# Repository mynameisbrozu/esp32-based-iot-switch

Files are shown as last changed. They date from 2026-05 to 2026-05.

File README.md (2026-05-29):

# ESP32 based iot switch
An IOT switch designed in KiCad based on ESP32-C5 and GDEY037T03 e-paper display. All electronic components were sourced from AliExpress (wanted to try something I guess).
## ESP32-C5
32-bit single-core RISC-V MCU running at up to 240 MHz with 29 GPIOs.

- Dual-band 2.4/5 GHz connectivity
- Wi-Fi 6
- BLE 5
- Zigbee and Thread support

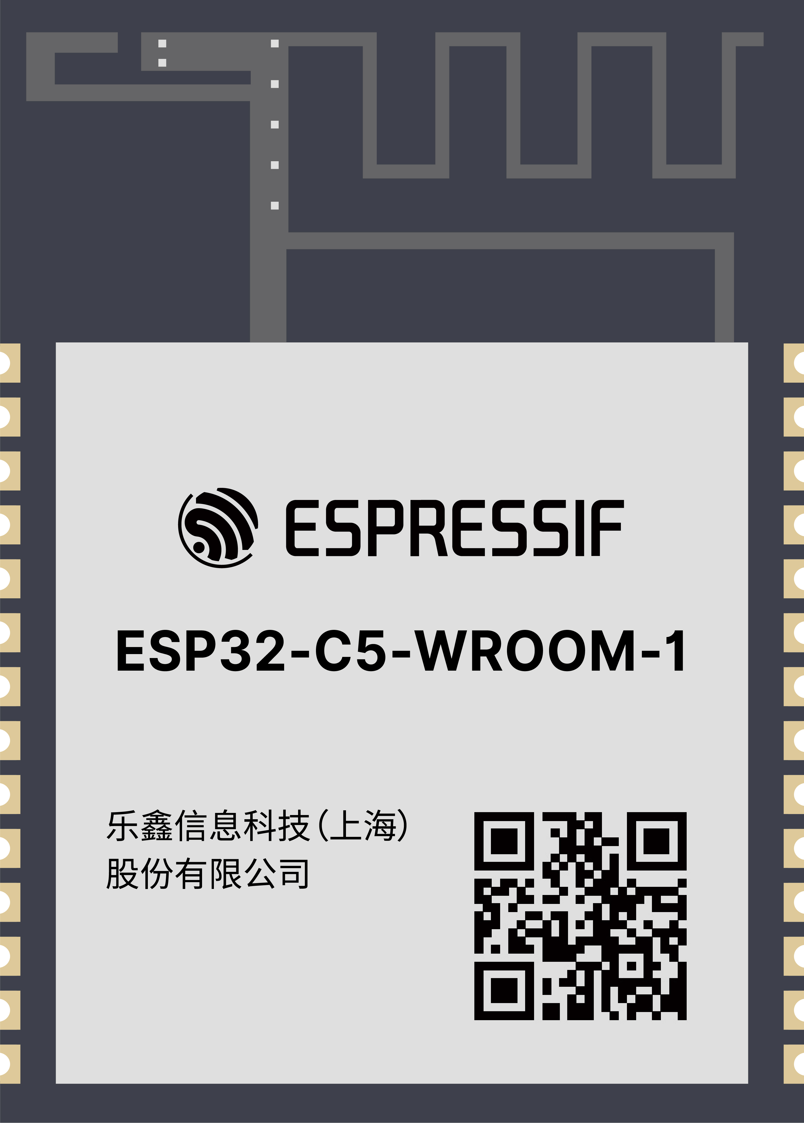
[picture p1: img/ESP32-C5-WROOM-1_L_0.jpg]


## GooDisplay GDEY037T03
3.7" black-and-white e-paper display.
- 240x416 resolution.
- 4-wire SPI interface

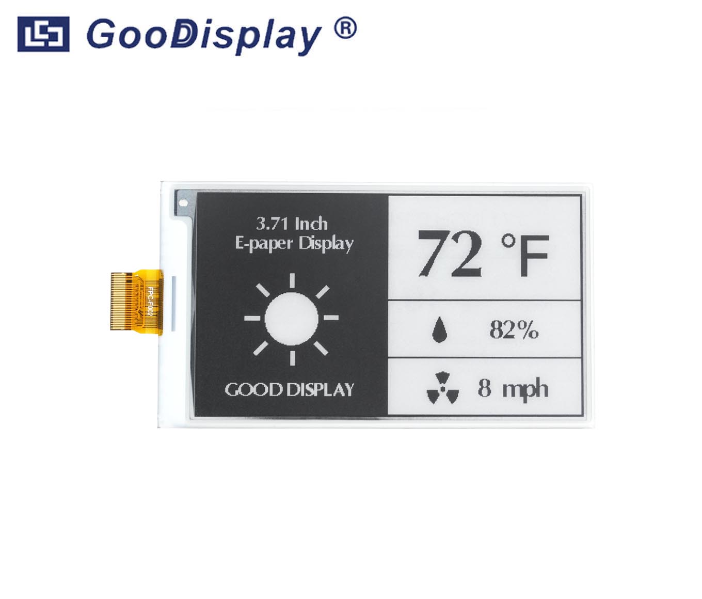
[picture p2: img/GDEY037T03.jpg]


## 1. Part sourcing and Power Budget
All components used in this project were sourced from AliExpress.

A simple system block diagram was created early in the design process to estimate the power budget and guide component selection.

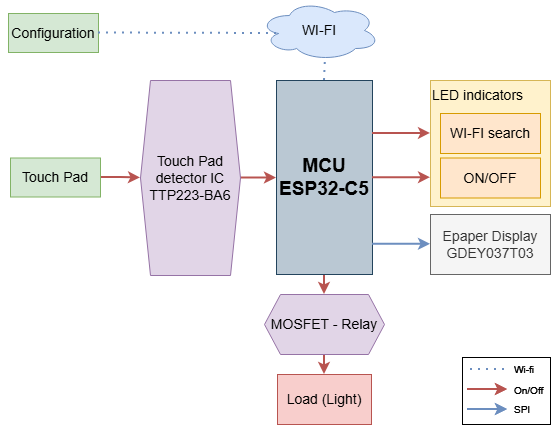
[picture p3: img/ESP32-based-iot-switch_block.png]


The BOM was progressively refined while developing the schematic. BOM in "spreadsheets" folder.
## 2. Schematic and PCB layout
The schematic was designed using reference circuits from datasheets, application notes, and technical articles.

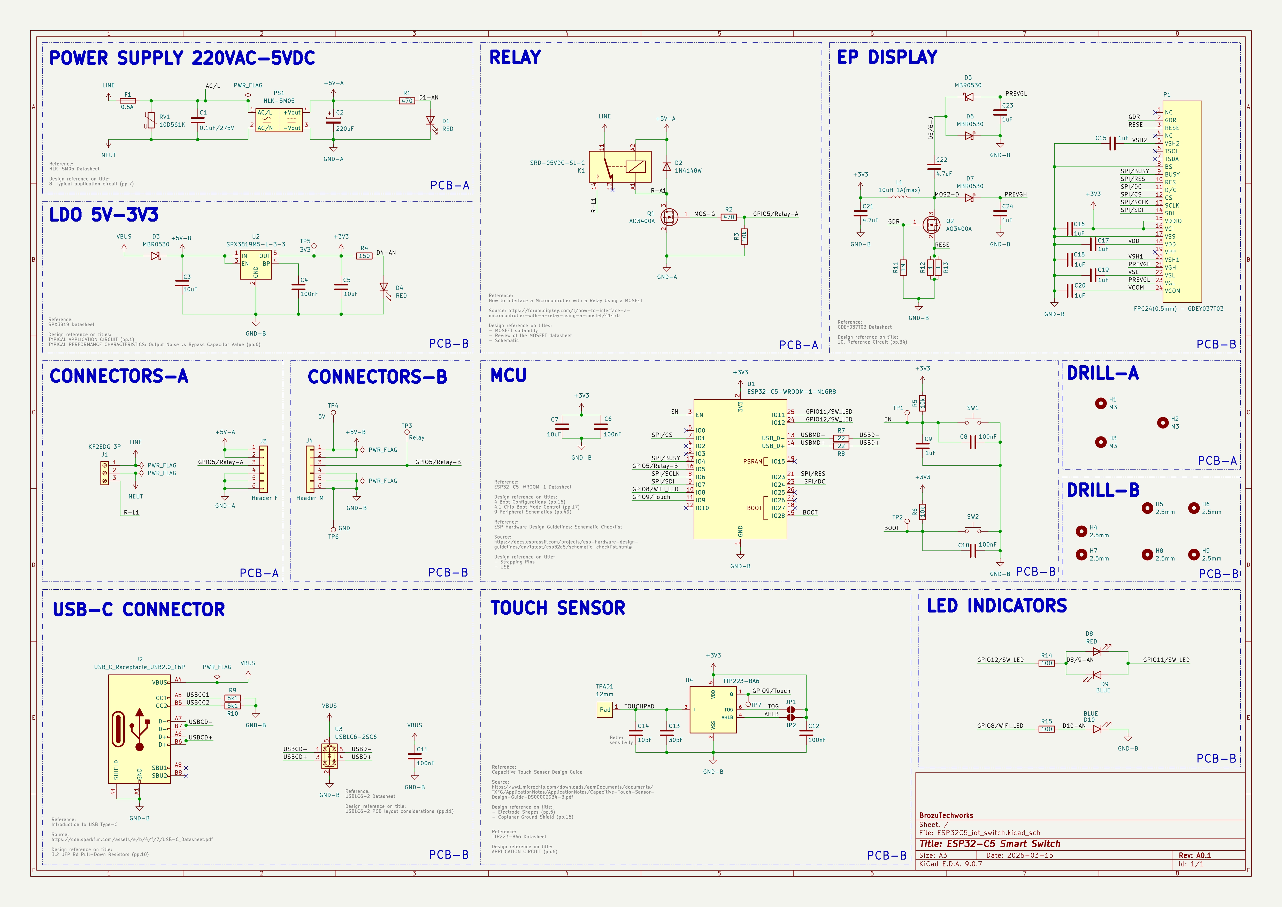
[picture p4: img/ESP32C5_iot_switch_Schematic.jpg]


The PCB layout show some of the mechanical constraints of the enclosure.

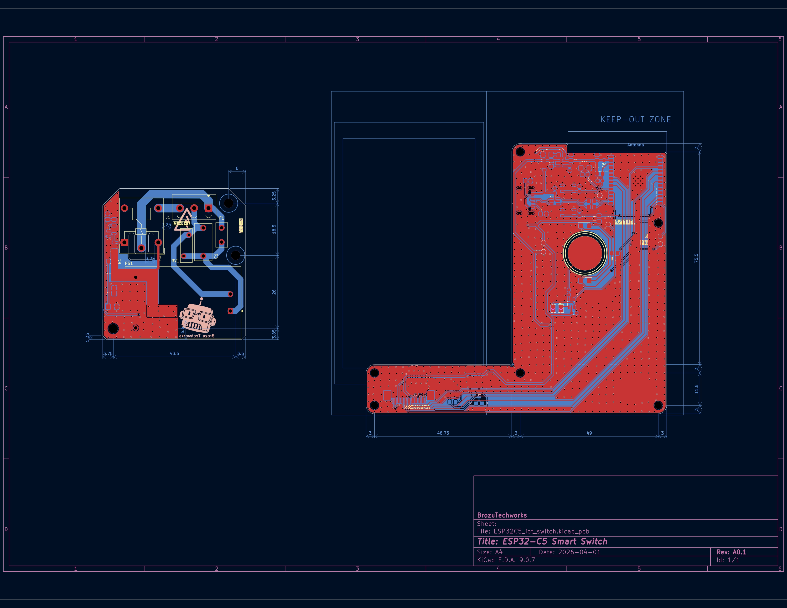
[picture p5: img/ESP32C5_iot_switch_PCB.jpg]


|  |  |
|---|---|
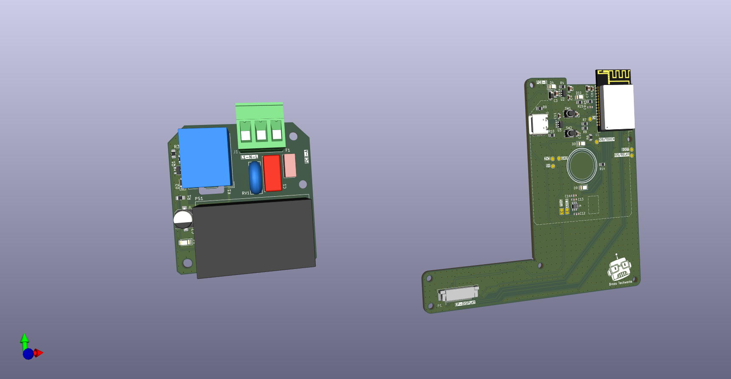
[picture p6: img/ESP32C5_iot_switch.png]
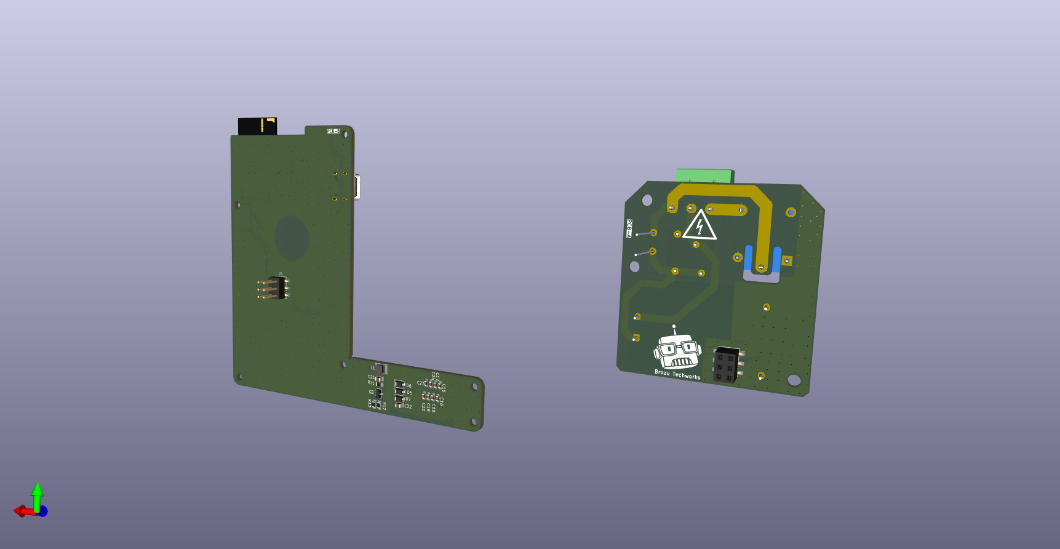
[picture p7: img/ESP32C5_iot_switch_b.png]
|  |  |
## 3. PCB Assembly
All components were manually assembled and soldered with a soldering iron (yeah...). 

PCB-A
|  |  |
|---|---|
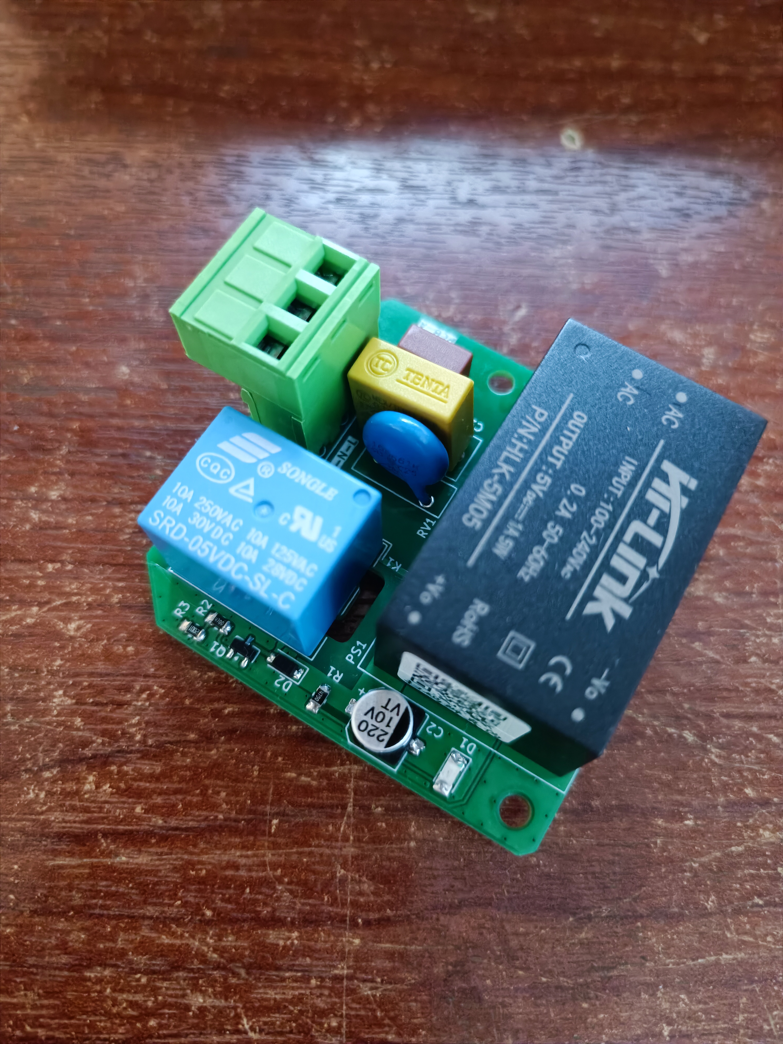
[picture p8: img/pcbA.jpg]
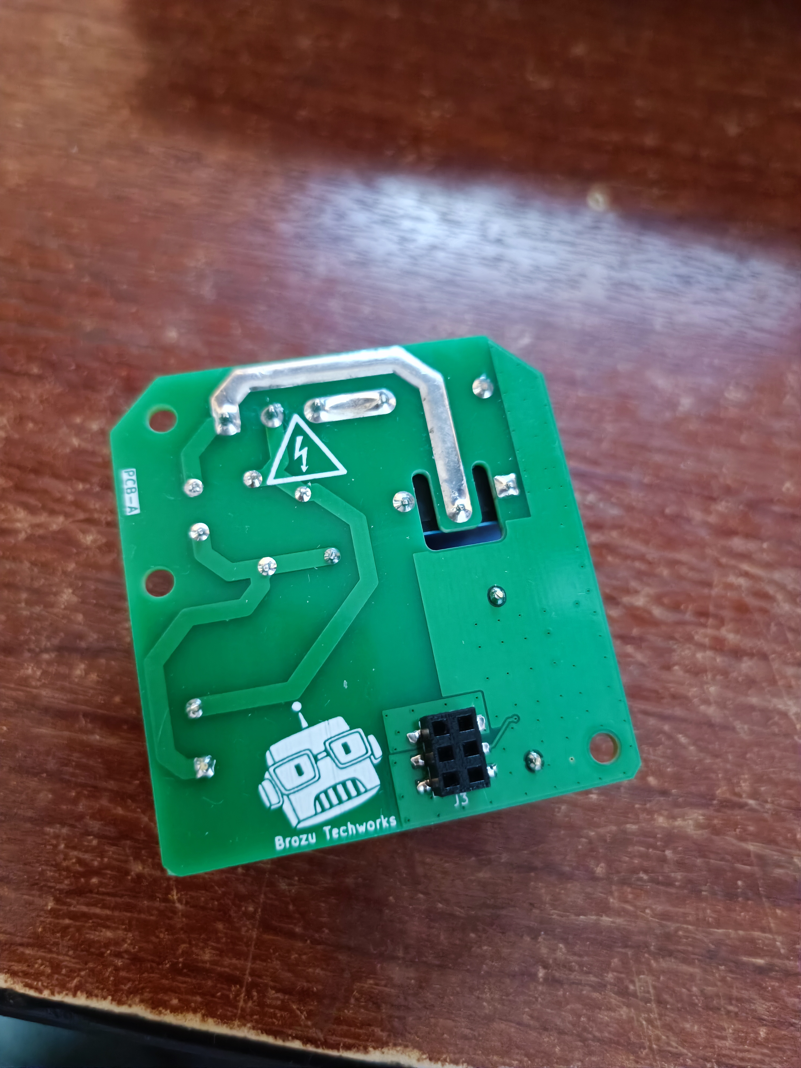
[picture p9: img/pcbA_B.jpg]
|  |  |

PCB-B
|  |  |
|---|---|
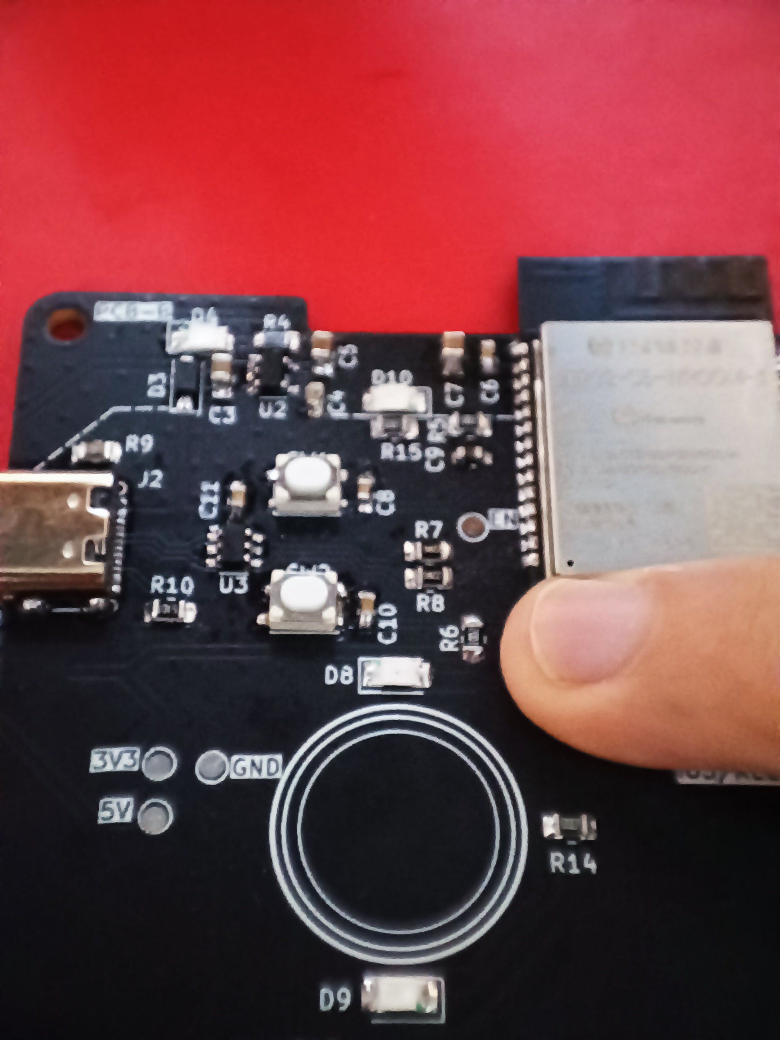
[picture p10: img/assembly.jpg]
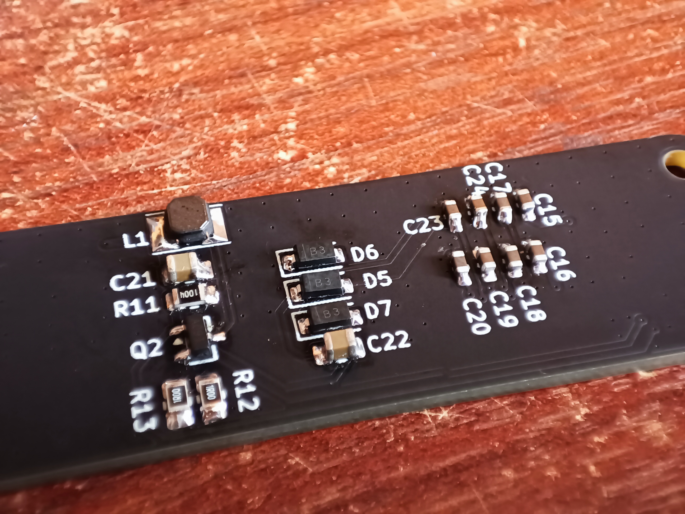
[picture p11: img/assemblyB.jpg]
|  |  |
## 4. Firmware...
Firmware development is still in progress.

Current work focuses on developing an integration library between the GDEY037T03 e-paper display and the Adafruit GFX library.

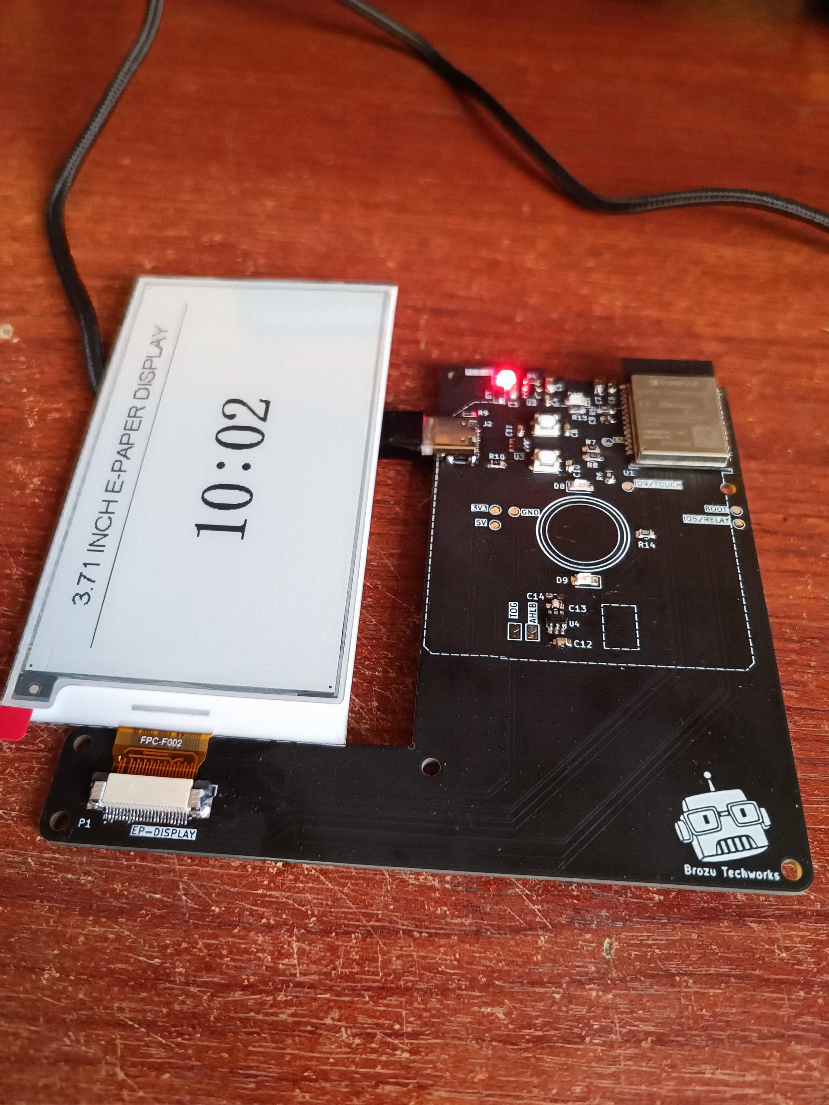
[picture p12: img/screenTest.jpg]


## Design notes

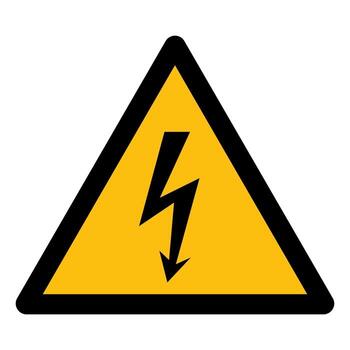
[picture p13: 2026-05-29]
PCB/silkscreen/danger-high-voltage.jpg

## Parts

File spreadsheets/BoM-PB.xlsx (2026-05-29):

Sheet: BoM
Bill of Materials
Block | Device | Description | Qty. | Buy Link | Pitch/Size
Power supply | 10D561K | Varistor | 1 | https://es.aliexpress.com/item/1005002576145968.html | 7.5mm
Relay | 1N4148W | FS Diode 75V 0.15 A | 1 | https://es.aliexpress.com/item/1005010653199938.html | SOD-123
Display | AO3400A | N-Channel MOSFET | 1 | https://es.aliexpress.com/item/1005007115799728.html | SOT-23
Relay | AO3400A | N-Channel MOSFET | 1 | https://es.aliexpress.com/item/1005007115799728.html | SOT-23
Display | Ceramic capacitor | 1uF 25V X7R | 8 | https://es.aliexpress.com/item/1005007464553853.html | 0603
Display | Ceramic capacitor | 4.7uF 25V X7R | 2 | https://es.aliexpress.com/item/1005007464553853.html | 0805
MCU | Ceramic capacitor | 100nF 25V X7R | 1 | https://es.aliexpress.com/item/1005007470747384.html | 0603
MCU | Ceramic capacitor | 100nF 25V X7R | 2 | https://es.aliexpress.com/item/1005007470747384.html | 0603
MCU | Ceramic capacitor | 10uF 25V X7R | 1 | https://es.aliexpress.com/item/1005007464553853.html | 0805
MCU | Ceramic capacitor | 1uF 25V X7R | 1 | https://es.aliexpress.com/item/1005007470747384.html | 0603
Power regulator | Ceramic capacitor | 100nF 25V X7R | 1 | https://es.aliexpress.com/item/1005007470747384.html | 0603
Power regulator | Ceramic capacitor | 10uF 25V X7R | 2 | https://es.aliexpress.com/item/1005007464553853.html | 0805
Touch button | Ceramic capacitor | 100nF 25V X7R | 1 | https://es.aliexpress.com/item/1005007470747384.html | 0603
Touch button | Ceramic capacitor | 10pF | 1 | https://es.aliexpress.com/item/1005006186888242.html | 0603
Touch button | Ceramic capacitor | 30pF | 1 | https://es.aliexpress.com/item/1005006186888242.html | 0603
USB | Ceramic capacitor | 100nF 25V X7R | 1 | https://es.aliexpress.com/item/1005007470747384.html | 0603
MCU | ESP32-C5-WROOM-1-N16R8 | 8MB FLASH/8MB PSRAM/PCB ANTENNA | 1 | https://es.aliexpress.com/item/1005008833493839.html | -
Power supply | Filter capacitor | 10V 220uF | 1 | https://es.aliexpress.com/item/33044078876.html | 6.3x5.4mm
Display | FPC connector | 24 pin Drawer Top | 1 | https://es.aliexpress.com/item/1005006818638048.html | 0.5mm
Display | GDEY037T03 | E-Paper display | 1 | https://es.aliexpress.com/item/1005005858184704.html | 3.71"
Power supply | HLK-5M05 | 5V - 1A | 1 | https://www.aliexpress.com/item/1005006175235171.html | -
Display | Inductor | 10uH | 1 | https://es.aliexpress.com/item/1005011794990023.html | NR3015
Connectors | KF2EDG | 300V 10A 3P Straight | 1 | https://es.aliexpress.com/item/1005007488495840.html | 5.08mm
Indicators | LED | Blue | 2 | https://es.aliexpress.com/item/1005005431944057.html | 1206
Indicators | LED | Red | 1 | https://es.aliexpress.com/item/1005005431944057.html | 1206
Power regulator | LED | Red | 1 | https://es.aliexpress.com/item/1005005431944057.html | 1206
Power supply | LED | Red | 1 | https://es.aliexpress.com/item/1005005431944057.html | 1206
Display | MBR0530 | Schottky diode 30V 430mV 0.5A | 3 | https://es.aliexpress.com/item/1005005945742136.html | SOD-123
Power regulator | MBR0530 | Schottky diode 30V 430mV 0.5A | 1 | https://es.aliexpress.com/item/1005005945742136.html | SOD-123
Connectors | Pin Header | SMD Male B3.5 2x3 | 1 | https://es.aliexpress.com/item/1005006283746201.html | 2.54mm
Connectors | Pin Socket | SMD Female PH5 2x3 | 1 | https://es.aliexpress.com/item/1005006283746201.html | 2.54mm
Display | Resistor | 1 ohm | 2 | https://es.aliexpress.com/item/1005006734007935.html | 0805
Display | Resistor | 1M ohm | 1 | https://es.aliexpress.com/item/1005006734007935.html | 0805
Indicators | Resistor | 100 ohm | 2 | https://es.aliexpress.com/item/1005006734007935.html | 0805
MCU | Resistor | 10k ohm | 2 | https://es.aliexpress.com/item/1005006734007935.html | 0805
Power regulator | Resistor | 150 ohm | 1 | https://es.aliexpress.com/item/1005006734007935.html | 0805
Power supply | Resistor | 470 ohm | 1 | https://es.aliexpress.com/item/1005006734007935.html | 0805
Relay | Resistor | 10k ohm | 1 | https://es.aliexpress.com/item/1005006734007935.html | 0805
Relay | Resistor | 470 ohm | 1 | https://es.aliexpress.com/item/1005006734007935.html | 0805
USB | Resistor | 22 ohm | 2 | https://es.aliexpress.com/item/1005006734007935.html | 0805
USB | Resistor | 5.1k ohm | 2 | https://es.aliexpress.com/item/1005006734007935.html | 0805
Power supply | Safety capacitor | 0.1uF - 275 VAC | 1 | https://es.aliexpress.com/item/1005002538662756.html | 10mm
Power supply | Slow Fuse | 0.5A - 250 VAC | 1 | https://es.aliexpress.com/item/32913238799.html | 5mm
MCU | SMD Button | 12V 50mA 4 pin | 2 | https://es.aliexpress.com/item/4000555847543.html | 3*4*2.5mm
Power regulator | SPX3819M5-L-3.3 | LDO 3.3V regulator | 1 | https://es.aliexpress.com/item/1005005809360574.html | SOT-23-5
Relay | SRD-05VDC-SL-C | 5VDC 10A 250VAC | 1 | https://es.aliexpress.com/item/1005005821974016.html | -
Touch button | TTP223-BA6 | Touch pad detector IC | 1 | https://es.aliexpress.com/item/1005006884029473.html | SOT-23-6
USB | USB Type C | Female Vertically | 1 | https://es.aliexpress.com/item/1005006353547160.html | 16 pin
USB | USBLC6-2SC6 | ESD Protector | 1 | https://es.aliexpress.com/item/1005007348100430.html | SOT-23-6

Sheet: Power_budget
Power Budget
Device | Current |  | Supply |  |  | 3.3V Supply |  | 5V Supply
MCU | 397 | mA | 0.5A 3.3V | 1A 5V | Total Current | 423 | mA | 0.519 | A
3.3V LEDs | 15 | mA |  |  | %Load | 84.6% |  | 51.9%
Display | 10 | mA
Touchpad IC | 1 | mA
5V LED | 6 | mA
Relay | 90 | mA

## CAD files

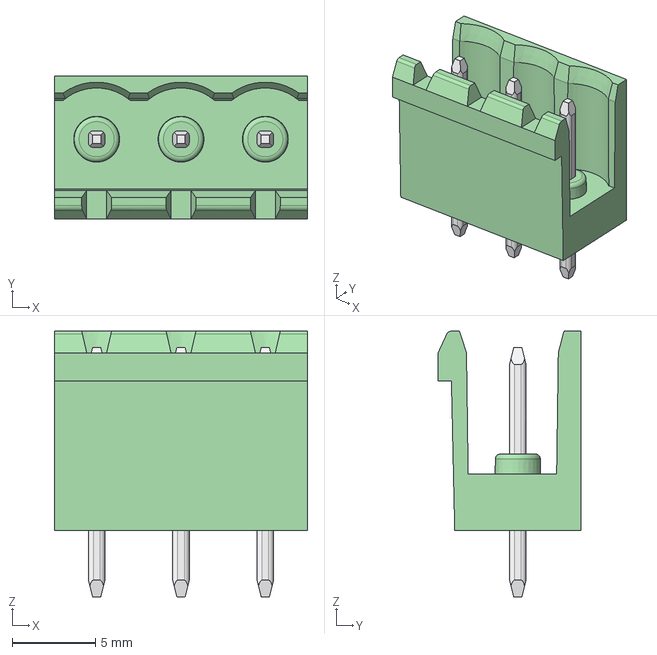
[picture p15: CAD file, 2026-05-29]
PCB/ext-3Dmodels/2EDGV-5_08-03P-1Y-100A&Z(H).stp
15.2 x 8.60 x 16.0 mm

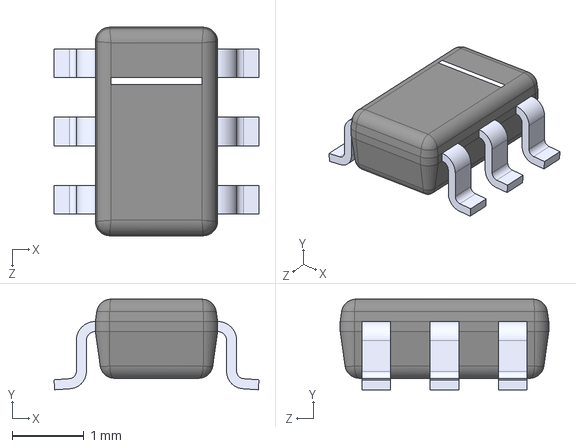
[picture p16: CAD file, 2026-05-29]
PCB/ext-libraries/TTP223-BA6/TTP223-BA6.step
2.85 x 1.26 x 2.90 mm

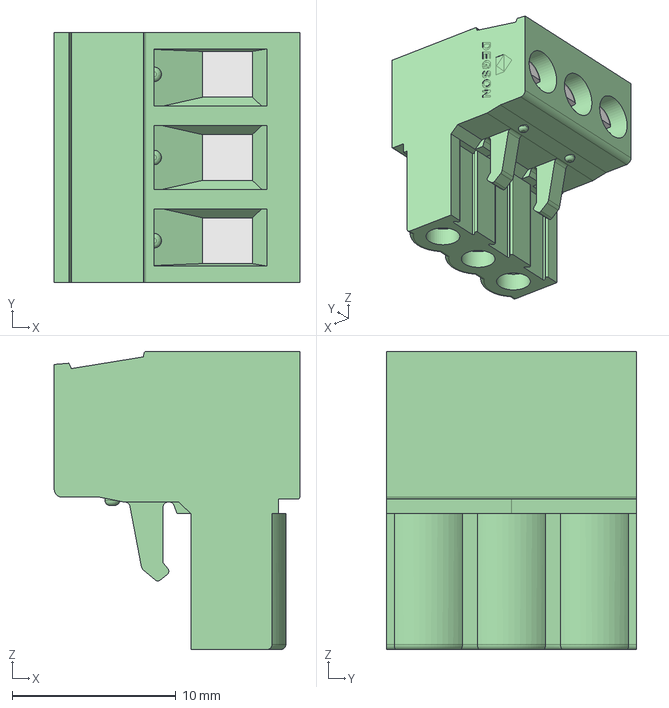
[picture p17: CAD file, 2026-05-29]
PCB/ext-3Dmodels/2EDGK-5.08-03P-14-1000A&Z(H).stp
15.0 x 15.2 x 18.2 mm

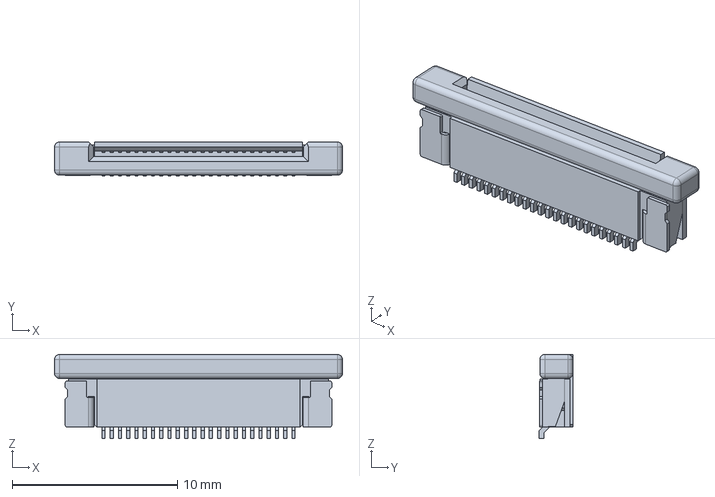
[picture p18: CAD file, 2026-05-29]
PCB/ext-3Dmodels/FPC_24P_0.5mm.STEP
17.4 x 2.05 x 5.11 mm

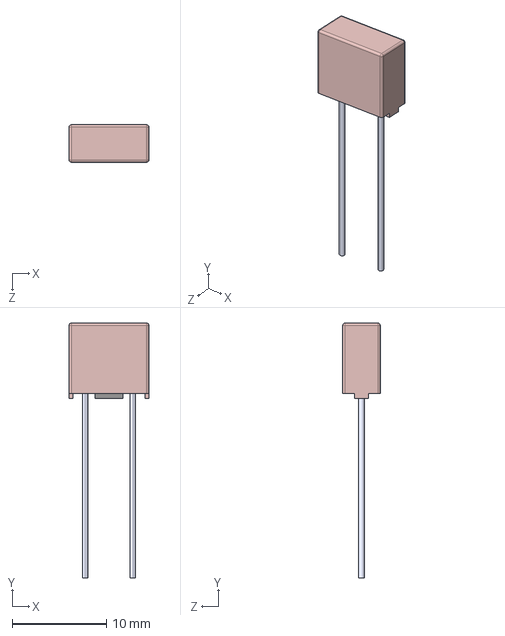
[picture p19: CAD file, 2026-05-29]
PCB/ext-3Dmodels/FUSE_littlefuse.STEP
8.50 x 27.1 x 4.00 mm

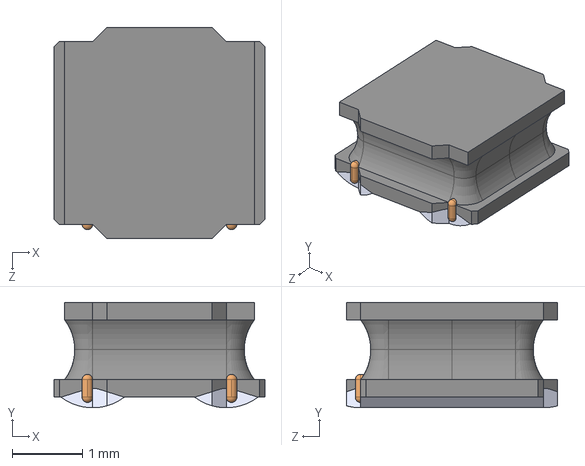
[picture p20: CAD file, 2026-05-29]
PCB/ext-3Dmodels/NR3015T100M.STEP
3.00 x 1.50 x 3.00 mm

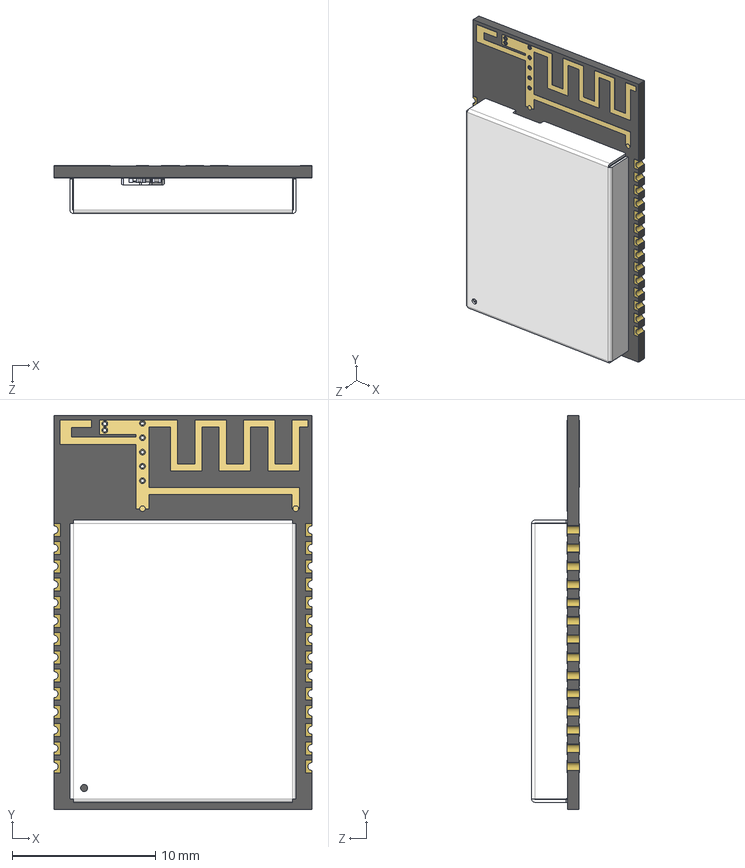
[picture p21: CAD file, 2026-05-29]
PCB/ext-3Dmodels/ESP32-C5-WROOM-1_V1_3_20250619_0.STEP
18.0 x 27.5 x 3.35 mm
uid__2428
LFD182G45MJ5D658.xtd
XTAL2016.xtd
R0201_20210301.xtd x 9
C0201_20210301.xtd x 23
C0402_20210301.xtd x 3
ESP32_6x6_20210301.xtd
SOP8_rev1_20210308.xtd
L0201_20210301.xtd x 4
SOD882.xtd
Imported
Submodel-DB-ANT-TYPEB-top-
Submodel_DB-ANT-TYPEB-bottom
pad-0.8mm x 28
ShieldBox_ESP32-C5-WROOM-1_V1.1_20240603

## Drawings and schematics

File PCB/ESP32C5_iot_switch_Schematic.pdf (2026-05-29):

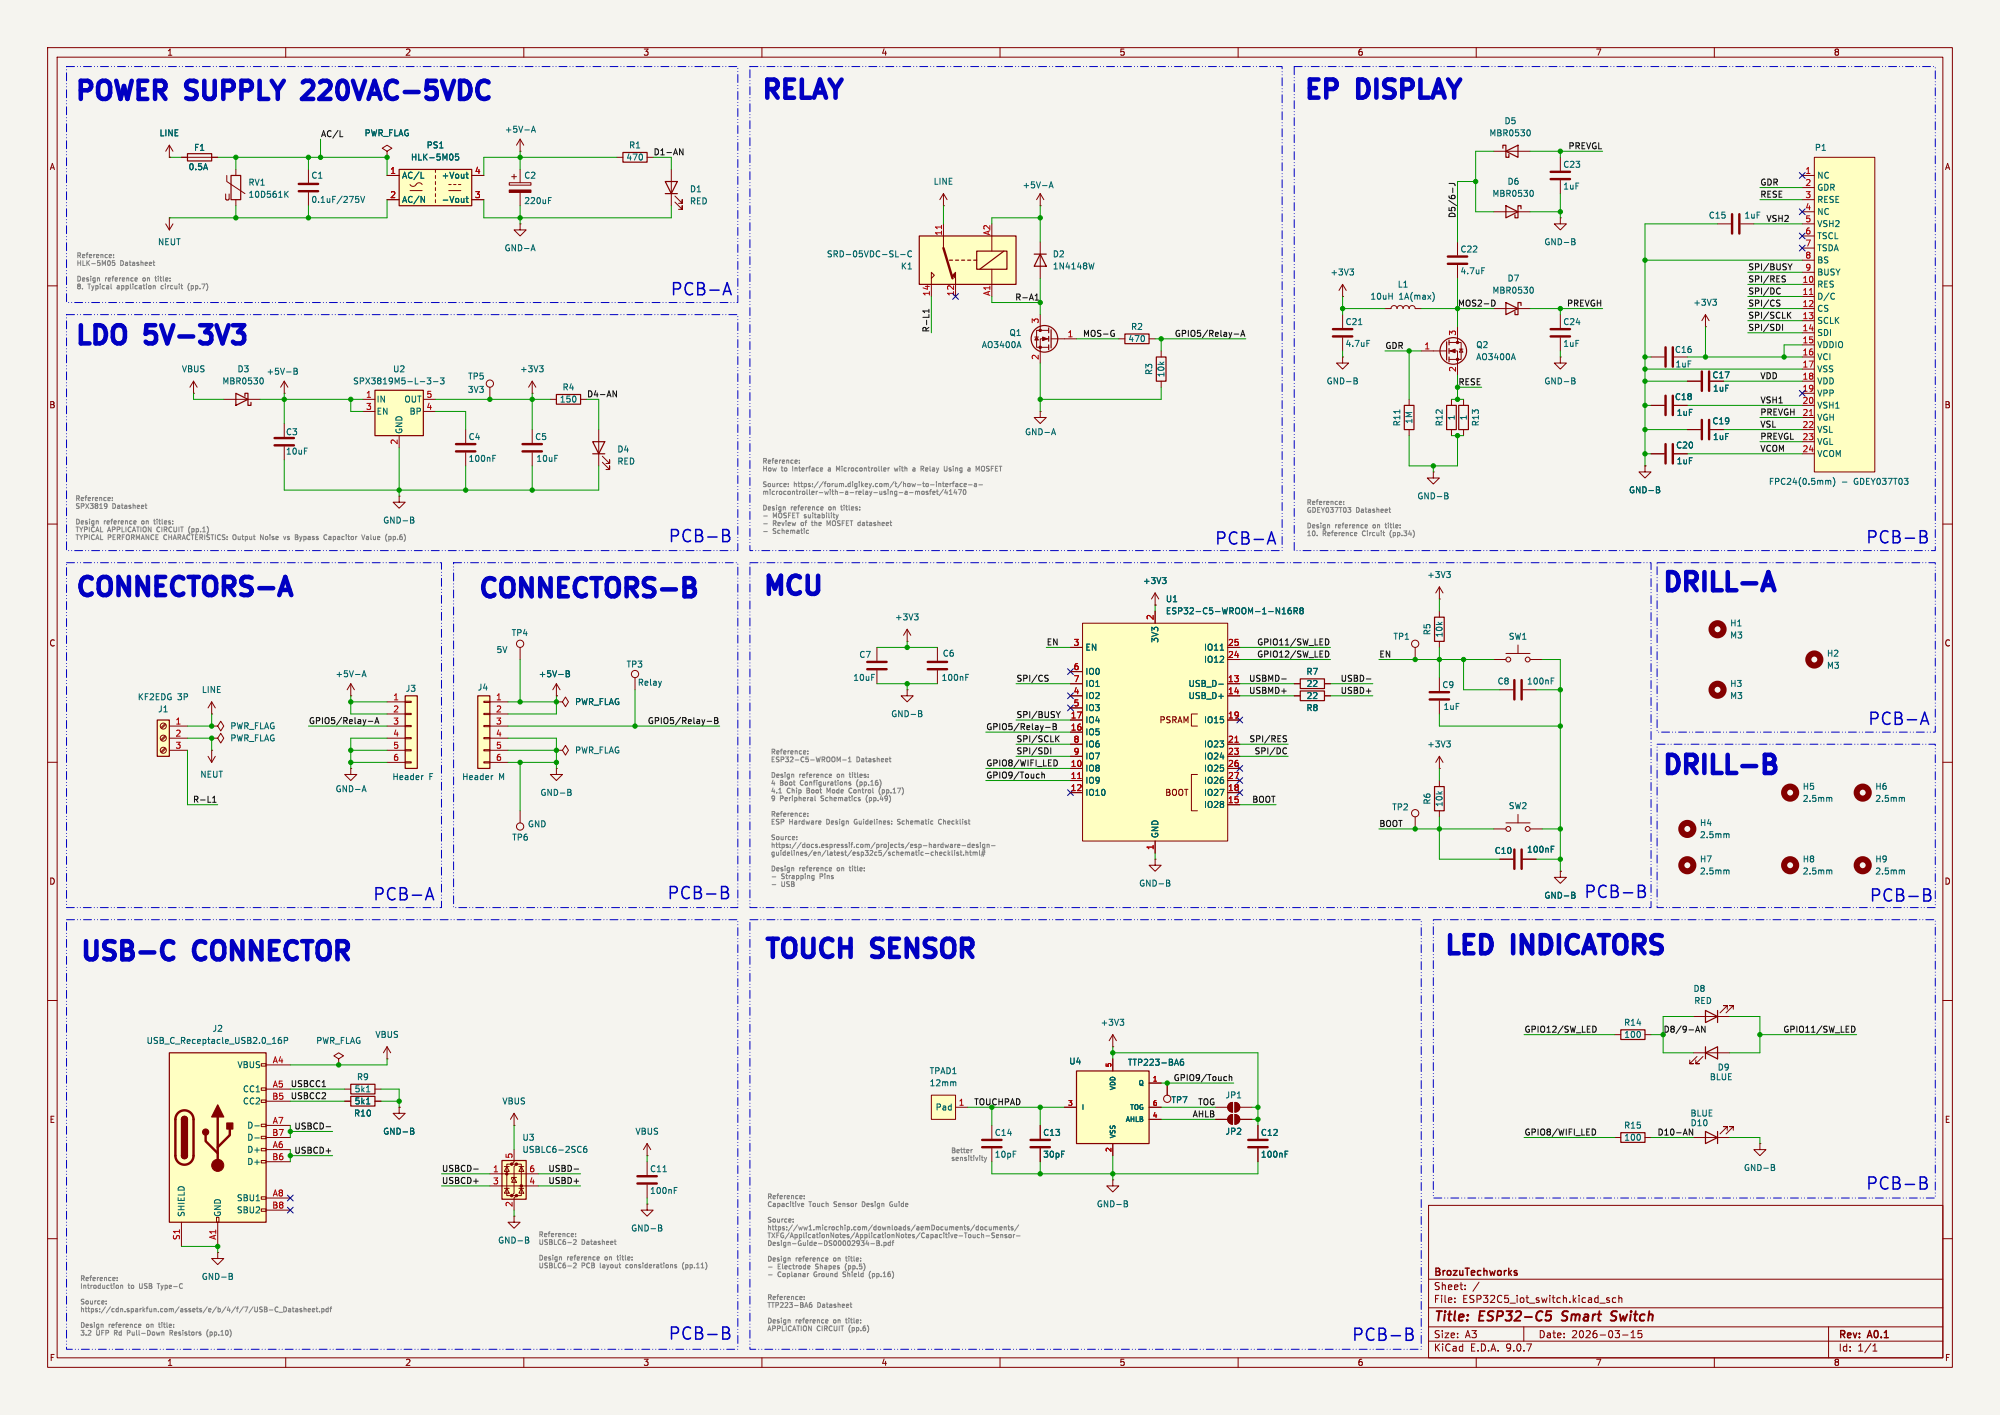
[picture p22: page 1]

VDD GPIO9/Touch SPI/CS

- Review of the MOSFET datasheet - Schematic PCB-B

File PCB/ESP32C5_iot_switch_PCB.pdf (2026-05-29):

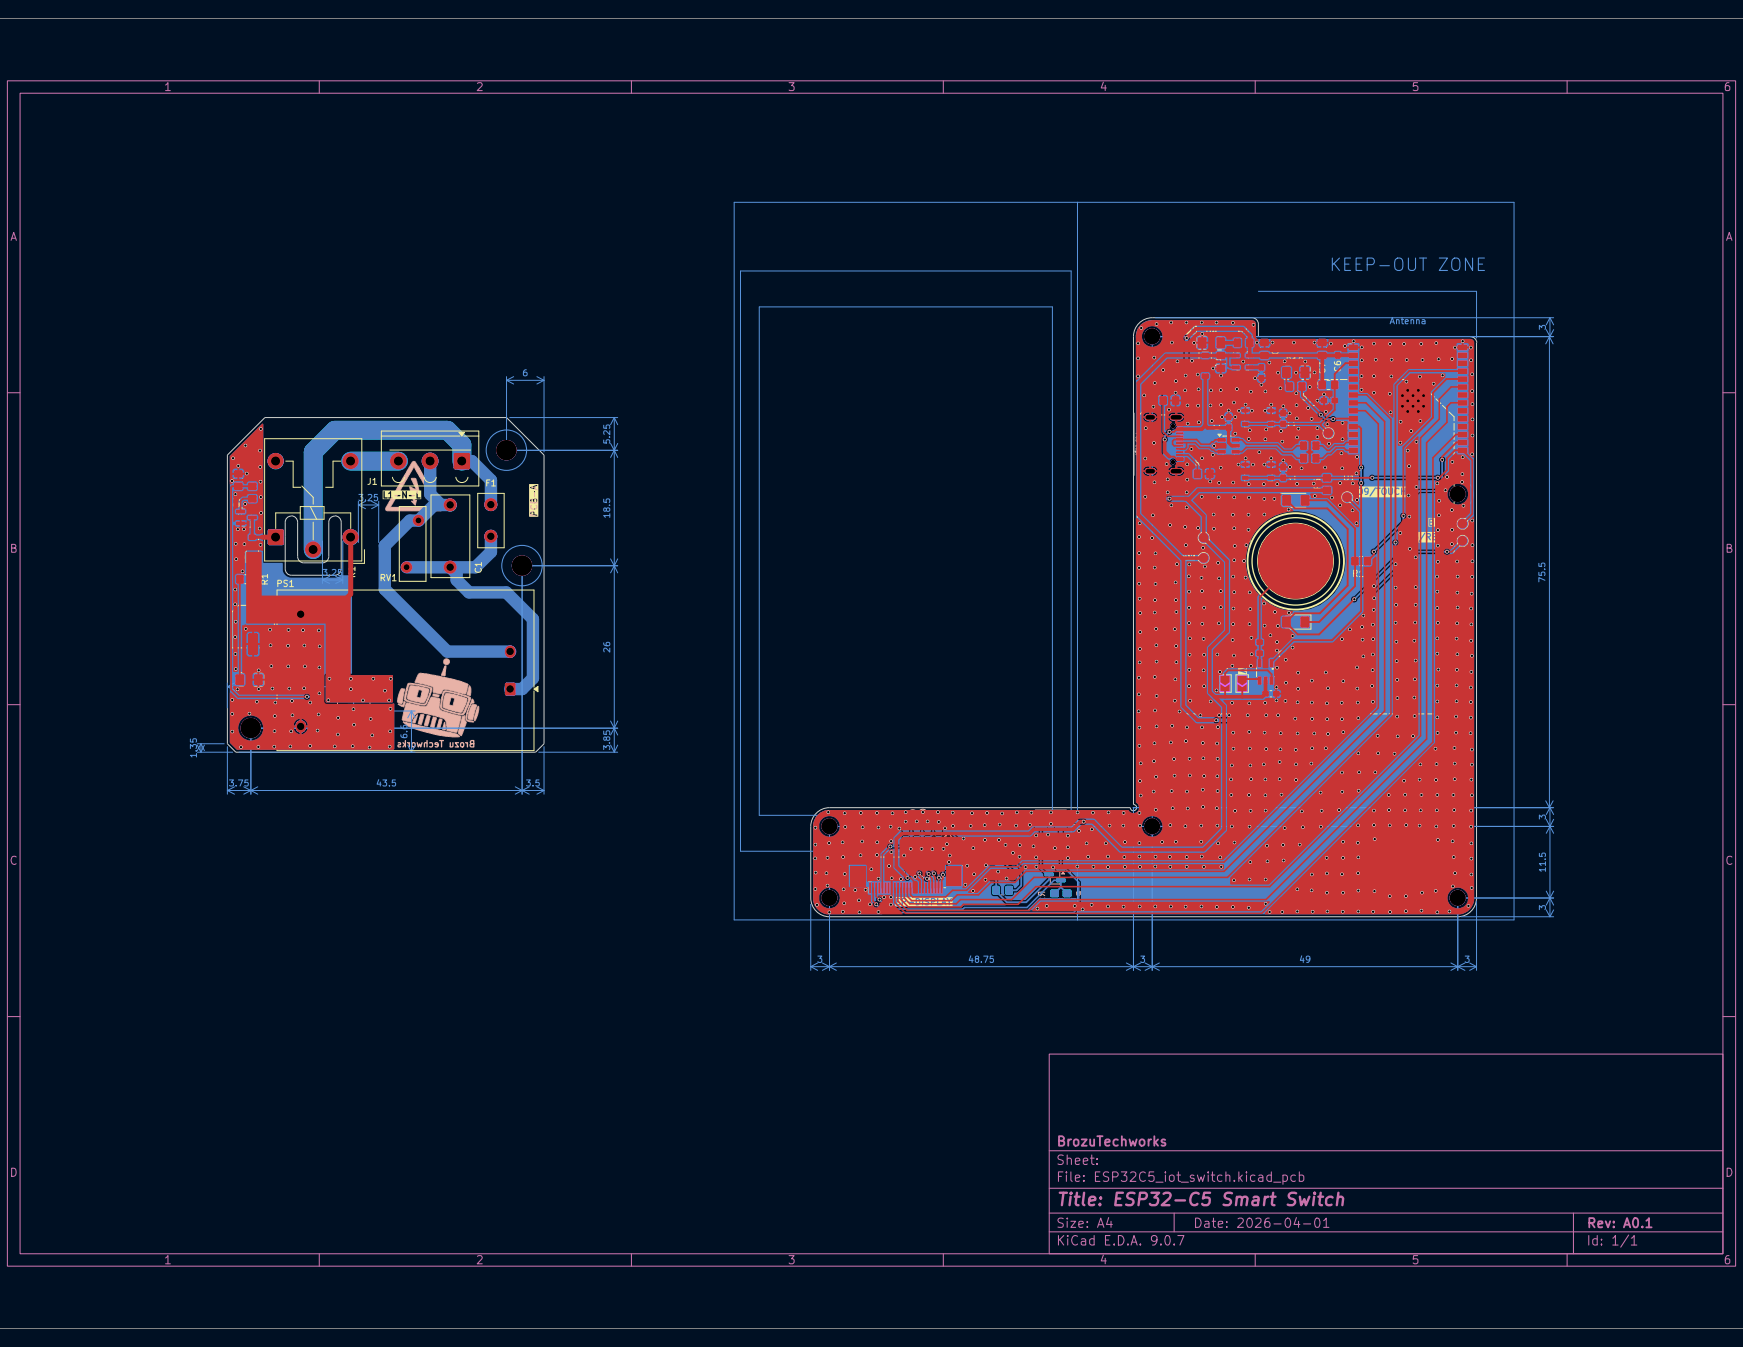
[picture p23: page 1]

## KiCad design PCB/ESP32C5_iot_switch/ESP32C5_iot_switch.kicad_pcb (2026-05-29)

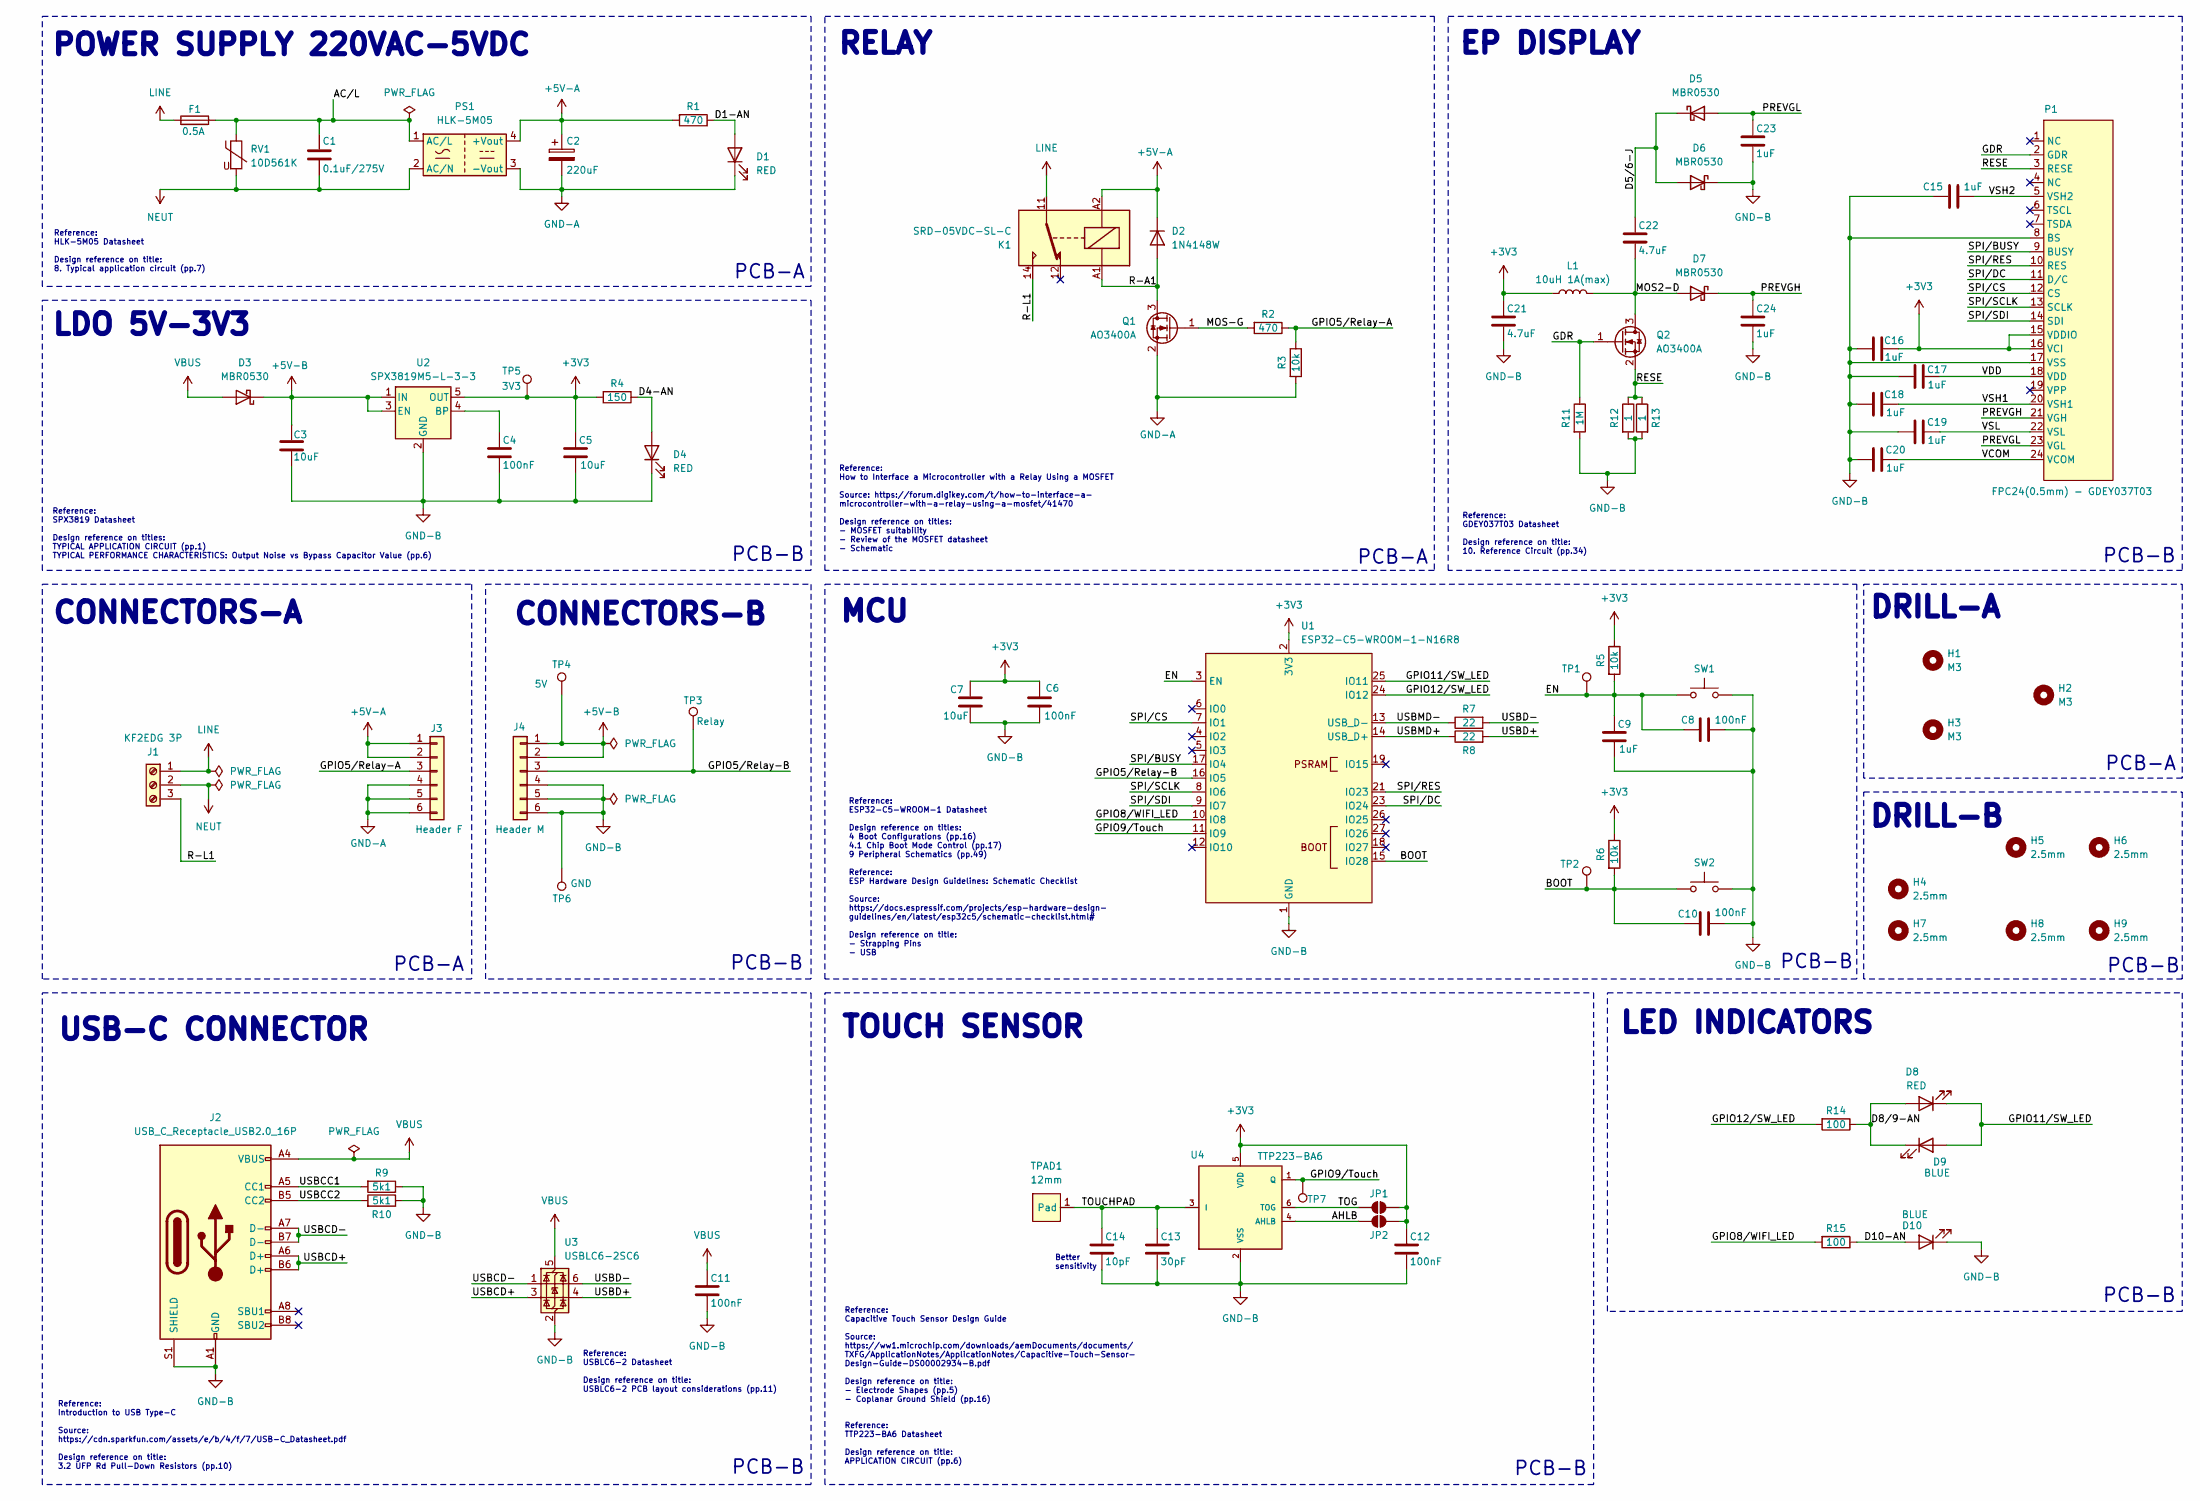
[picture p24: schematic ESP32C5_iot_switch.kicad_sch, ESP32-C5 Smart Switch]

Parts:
C1: 0.1uF/275V; C_Rect_L13.0mm_W6.0mm_P10.00mm_FKS3_FKP3_MKS4
C2: 220uF; CP_Elec_6.3x5.4
C3, C5, C7: 10uF; C_0805_2012Metric_Pad1.18x1.45mm_HandSolder
C4, C6, C8, C10, C11, C12: 100nF; C_0603_1608Metric_Pad1.08x0.95mm_HandSolder
C9, C15, C16, C17, C18, C19, C20, C23, C24: 1uF; C_0603_1608Metric_Pad1.08x0.95mm_HandSolder
C13: 30pF; C_0603_1608Metric_Pad1.08x0.95mm_HandSolder
C14: 10pF; C_0603_1608Metric_Pad1.08x0.95mm_HandSolder
C21, C22: 4.7uF; C_0805_2012Metric_Pad1.18x1.45mm_HandSolder
D1, D4, D8: RED; LED_1206_3216Metric_Pad1.42x1.75mm_HandSolder
D2: 1N4148W; D_SOD-123
D3, D5, D6, D7: MBR0530; D_SOD-123
D9, D10: BLUE; LED_1206_3216Metric_Pad1.42x1.75mm_HandSolder
F1: 0.5A; Fuse_Littelfuse_395Series
H1, H2, H3: M3; MountingHole_3.2mm_M3
H4, H5, H6, H7, H8, H9: 2.5mm; MountingHole_2.5mm
J1: KF2EDG 3P; TerminalBloc_2EDGV-2EDGK_5.08mm_01x03P
J2: USB_C_Receptacle_USB2.0_16P; USB_C_Receptacle_GCT_USB4105-xx-A_16P_TopMnt_Horizontal
J3: Header F; PinSocket_2x03_P2.54mm_Vertical_SMD
J4: Header M; PinHeader_2x03_P2.54mm_Vertical_SMD
JP1, JP2: SolderJumper_2_Open; SolderJumper-2_P1.3mm_Open_TrianglePad1.0x1.5mm
K1: SRD-05VDC-SL-C; Relay_SPDT_Hongfa_HF3F-L-xx-1ZL1T
L1: 10uH 1A(max); L_Taiyo-Yuden_NR-30xx_HandSoldering
P1: FPC24(0.5mm) - GDEY037T03; FPC_LW05201-24
PS1: HLK-5M05; Converter_ACDC_Hi-Link_HLK-5Mxx
Q1, Q2: AO3400A; SOT-23
R1, R2: 470; R_0805_2012Metric_Pad1.20x1.40mm_HandSolder
R3, R5, R6: 10k; R_0805_2012Metric_Pad1.20x1.40mm_HandSolder
R4: 150; R_0805_2012Metric_Pad1.20x1.40mm_HandSolder
R7, R8: 22; R_0805_2012Metric_Pad1.20x1.40mm_HandSolder
R9, R10: 5k1; R_0805_2012Metric_Pad1.20x1.40mm_HandSolder
R11: 1M; R_0805_2012Metric_Pad1.20x1.40mm_HandSolder
R12, R13: 1; R_0805_2012Metric_Pad1.20x1.40mm_HandSolder
R14, R15: 100; R_0805_2012Metric_Pad1.20x1.40mm_HandSolder
RV1: 10D561K; RV_Disc_D12mm_W4.3mm_P7.5mm
SW1, SW2: 3*4*2,5mm; SW_SPST_PTS810
TP1: EN; TestPoint_Pad_D1.5mm
TP2: BOOT; TestPoint_Pad_D1.5mm
TP3: Relay; TestPoint_Pad_D1.5mm
TP4: 5V; TestPoint_Pad_D1.5mm
TP5: 3V3; TestPoint_Pad_D1.5mm
TP6: GND; TestPoint_Pad_D1.5mm
TP7: Touch; TestPoint_Pad_D1.5mm
TPAD1: 12mm; touch_pad12mm
U1: ESP32-C5-WROOM-1-N16R8; ESP32-C5-WROOM-1
U2: SPX3819M5-L-3-3; SOT-23-5
U3: USBLC6-2SC6; SOT-23-6
U4: TTP223-BA6; SOT23-6

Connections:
+3V3: C5.1, C6.1, C7.1, C12.1, C16.1, C21.1, JP1.2 (B), JP2.2 (B), L1.1, P1.15 (VDDIO), P1.16 (VCI), R4.2, R5.1, R6.1, TP5.1, U1.2 (3V3), U2.5 (OUT), U4.5 (VDD)
+5V-A: C2.1, D2.1 (K), J3.1, J3.2, K1.A2, PS1.4 (+Vout), R1.2
+5V-B: C3.1, D3.1 (K), J4.1, J4.2, TP4.1, U2.1 (IN), U2.3 (EN)
/AC/L: C1.1, F1.2, PS1.1 (AC/L), RV1.1
/AHLB: JP2.1 (A), U4.4 (AHLB)
/BOOT: C10.2, R6.2, SW2.2, TP2.1, U1.15 (IO28)
/D1-AN: D1.2 (A), R1.1
/D4-AN: D4.2 (A), R4.1
/D5/6-J: C22.1, D5.1 (K), D6.2 (A)
/D8/9-AN: D8.2 (A), D9.1 (K), R14.1
/D10-AN: D10.2 (A), R15.1
/EN: C8.2, C9.1, R5.2, SW1.2, TP1.1, U1.3 (EN)
/GDR: P1.2 (GDR), Q2.1 (G), R11.1
/GPIO5/Relay-A: J3.3, R2.1, R3.1
/GPIO5/Relay-B: J4.3, TP3.1, U1.16 (IO5)
/GPIO8/WIFI_LED: R15.2, U1.10 (IO8)
/GPIO9/Touch: TP7.1, U1.11 (IO9), U4.1 (Q)
/GPIO11/SW_LED: D8.1 (K), D9.2 (A), U1.25 (IO11)
/GPIO12/SW_LED: R14.2, U1.24 (IO12)
/MOS2-D: C22.2, D7.2 (A), L1.2, Q2.3 (D)
/MOS-G: Q1.1 (G), R2.2
/PREVGH: C24.1, D7.1 (K), P1.21 (VGH)
/PREVGL: C23.1, D5.2 (A), P1.23 (VGL)
/R-A1: D2.2 (A), K1.A1, Q1.3 (D)
/R-L1: J1.3, K1.14
/RESE: P1.3 (RESE), Q2.2 (S), R12.1, R13.1
/SPI/BUSY: P1.9 (BUSY), U1.17 (IO4)
/SPI/CS: P1.12 (CS), U1.7 (IO1)
/SPI/DC: P1.11 (D/C), U1.23 (IO24)
/SPI/RES: P1.10 (RES), U1.21 (IO23)
/SPI/SCLK: P1.13 (SCLK), U1.8 (IO6)
/SPI/SDI: P1.14 (SDI), U1.9 (IO7)
/TOG: JP1.1 (A), U4.6 (TOG)
/TOUCHPAD: C13.1, C14.1, TPAD1.1 (Pad), U4.3 (I)
/USBCC1: J2.A5 (CC1), R9.2
/USBCC2: J2.B5 (CC2), R10.2
/USBCD+: J2.A6 (D+), J2.B6 (D+), U3.3 (I/O2)
/USBCD-: J2.A7 (D-), J2.B7 (D-), U3.1 (I/O1)
/USBD+: R8.2, U3.4 (I/O2)
/USBD-: R7.2, U3.6 (I/O1)
/USBMD+: R8.1, U1.14 (USB_D+)
/USBMD-: R7.1, U1.13 (USB_D-)
/VCOM: C20.1, P1.24 (VCOM)
/VDD: C17.1, P1.18 (VDD)
/VSH1: C18.1, P1.20 (VSH1)
/VSH2: C15.1, P1.5 (VSH2)
/VSL: C19.1, P1.22 (VSL)
GND-A: C2.2, D1.1 (K), J3.4, J3.5, J3.6, PS1.3 (-Vout), Q1.2 (S), R3.2
GND-B: C3.2, C4.2, C5.2, C6.2, C7.2, C8.1, C9.2, C10.1, C11.2, C12.2, C13.2, C14.2, C15.2, C16.2, C17.2, C18.2, C19.2, C20.2, C21.2, C23.2, C24.2, D4.1 (K), D6.1 (K), D10.1 (K), J2.A1 (GND), J2.A12 (GND), J2.B1 (GND), J2.B12 (GND), J2.S1 (SHIELD), J4.4, J4.5, J4.6, P1.8 (BS), P1.17 (VSS), R9.1, R10.1, R11.2, R12.2, R13.2, SW1.1, SW2.1, TP6.1, U1.1 (GND), U1.28 (GND), U1.29 (EPAD), U2.2 (GND), U3.2 (GND), U4.2 (VSS)
LINE: F1.1, J1.1, K1.11
NEUT: C1.2, J1.2, PS1.2 (AC/N), RV1.2
unnamed: C4.1, U2.4 (BP)
VBUS: C11.1, D3.2 (A), J2.A4 (VBUS), J2.A9 (VBUS), J2.B4 (VBUS), J2.B9 (VBUS), U3.5 (VBUS)

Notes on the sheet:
MCU
PCB-B
DRILL-A
PCB-A
USB-C CONNECTOR
Reference: GDEY037T03 Datasheet Design reference on title: 10. Reference Circuit (pp.34)
Reference: ESP32-C5-WROOM-1 Datasheet Design reference on titles: 4 Boot Configurations (pp.16) 4.1 Chip Boot Mode Control (pp.17) 9 Peripheral Schematics (pp.49) Reference: ESP Hardware Design Guidelines: Schematic Checklist Source: https://docs.espressif.com/projects/esp-hardware-design- guidelin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
Reference: TTP223-BA6 Datasheet Design reference on title: APPLICATION CIRCUIT (pp.6)
LDO 5V-3V3
Reference: HLK-5M05 Datasheet Design reference on title: 8. Typical application circuit (pp.7)
Reference: Capacitive Touch Sensor Design Guide Source: https://ww1.microchip.com/downloads/aemDocuments/documents/ TXFG/ApplicationNotes/ApplicationNotes/Capacitive-Touch-Sensor- Design-Guide-DS00002934-B.pdf Design reference on title: - Electrode Shapes (pp.5) - Coplanar Ground Shield (pp.16)
CONNECTORS-B
Reference: How to Interface a Microcontroller with a Relay Using a MOSFET Source: https://forum.digikey.com/t/how-to-interface-a- microcontroller-with-a-relay-using-a-mosfet/41470 Design reference on titles: - MOSFET suitability - Review of the MOSFET datasheet - Schematic
POWER SUPPLY 220VAC-5VDC
Reference: SPX3819 Datasheet Design reference on titles: TYPICAL APPLICATION CIRCUIT (pp.1) TYPICAL PERFORMANCE CHARACTERISTICS: Output Noise vs Bypass Capacitor Value (pp.6)
TOUCH SENSOR
Better sensitivity
Reference: Introduction to USB Type-C Source: https://cdn.sparkfun.com/assets/e/b/4/f/7/USB-C_Datasheet.pdf Design reference on title: 3.2 UFP Rd Pull-Down Resistors (pp.10)
EP DISPLAY
RELAY
LED INDICATORS
CONNECTORS-A
Reference: USBLC6-2 Datasheet Design reference on title: USBLC6-2 PCB layout considerations (pp.11)
DRILL-B

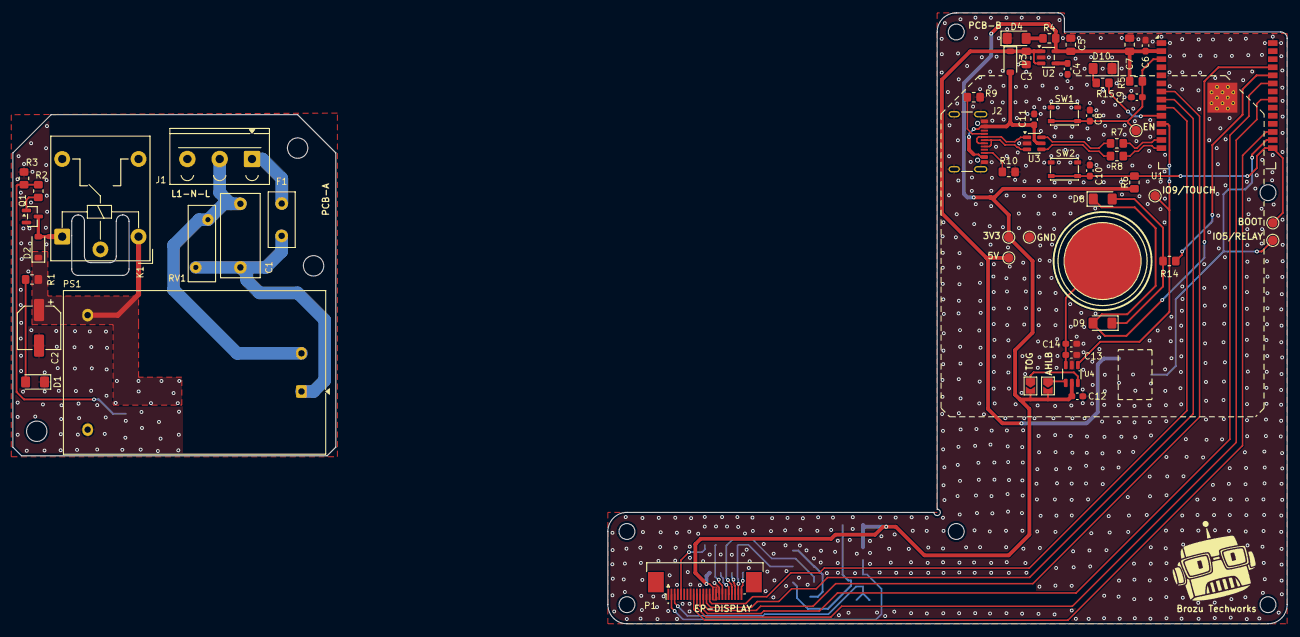
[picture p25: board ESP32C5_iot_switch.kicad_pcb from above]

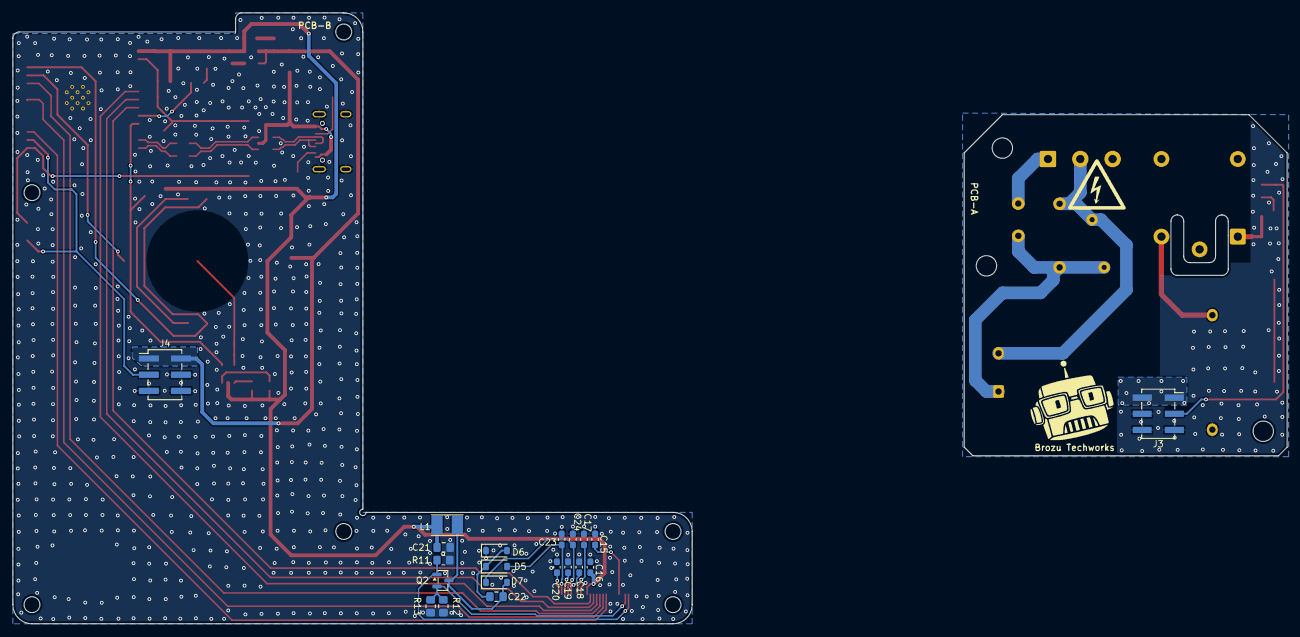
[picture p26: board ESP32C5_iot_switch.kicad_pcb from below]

Board: 2 copper layers, 106.8 x 96.0 mm, 86 parts (20 on the bottom side), 53 nets.

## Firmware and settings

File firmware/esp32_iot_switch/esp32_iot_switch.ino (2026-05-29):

#include <Arduino.h>

#define TOUCH_BUTTON 9
#define WIFI_LED 8
#define SW_LEDB 11
#define SW_LEDR 12

bool switchON = false;

void ARDUINO_ISR_ATTR touch() {
  if(switchON){
    digitalWrite(SW_LEDB, LOW);
    digitalWrite(SW_LEDR, HIGH);
    switchON = false;
  } else{
    digitalWrite(SW_LEDR, LOW);
    digitalWrite(SW_LEDB, HIGH);
    switchON = true;
  }
}

void setup() {
  pinMode(TOUCH_BUTTON, INPUT);
  pinMode(WIFI_LED, OUTPUT);
  pinMode(SW_LEDB, OUTPUT);
  pinMode(SW_LEDR, OUTPUT);
  digitalWrite(SW_LEDB, LOW);
  digitalWrite(SW_LEDR, HIGH);
  attachInterrupt(TOUCH_BUTTON, touch, RISING);
}

void loop() {
  // put your main code here, to run repeatedly:
  digitalWrite(WIFI_LED,HIGH);
  delay(2000);
  digitalWrite(WIFI_LED,LOW);
  delay(2000);
}

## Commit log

2026-05-29 Initial release
    [2EDGK-5.08-03P-14-1000A&Z(H).stp, 2EDGV-5_08-03P-1Y-100A&Z(H).stp, BoM-PB.xlsx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]
2026-11-04 Add: Firmware description, .ino and enclosure preview
